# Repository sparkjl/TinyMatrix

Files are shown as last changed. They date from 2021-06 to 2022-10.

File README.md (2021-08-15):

## TinyMatrix点阵控制器
> 基于STM32F103 Microcontroller，HUB75接口的点阵控制器。可通过1 x 4按键、串口指令控制LED点阵屏显示。

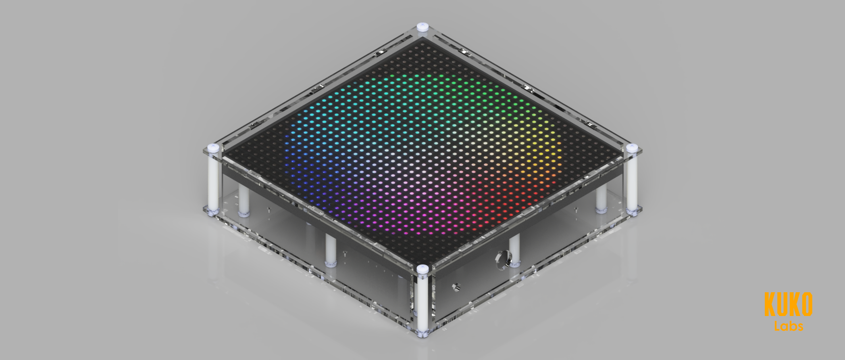
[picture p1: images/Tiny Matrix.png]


### 1. 硬件
#### 1.1. HUB75接口定义
Led点阵板的HUB75接口，一般以DC3-16P牛角座封装形式接入。通常Led点阵板的左右两侧各有一个HUB75接口IN、OUT，以实现多块Led点阵板的组合扩展。HUB75接口中：R1、G1、B1分别为上半屏的红、绿、蓝控制信号，R2、G2、B2分别为下半屏的红、绿、蓝控制信号，A、B、C、D、E为行选择信号，CLK为数据时钟信号，LAT为数据锁存信号，OE为输出使能信号，GND为信号地。

<div align="center">
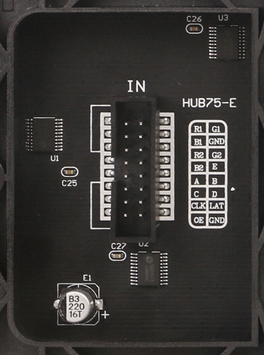
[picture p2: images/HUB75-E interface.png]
    
</div>

#### 1.2. HUB75扫描方式
将行扫描信号、行选择信号进行组合控制，就实现了整个Led点阵板的扫描显示。其具体实现过程如下：

<div align="center">
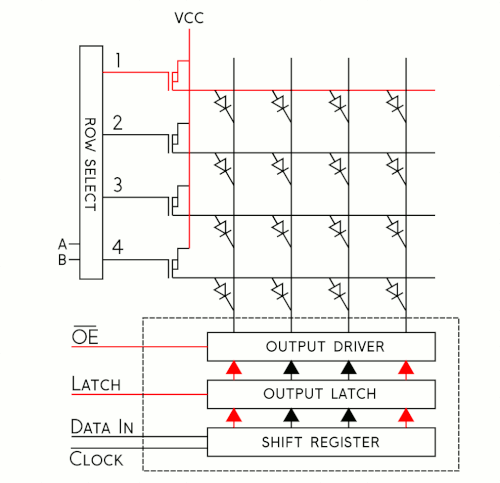
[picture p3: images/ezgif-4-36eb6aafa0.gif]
    
</div>

1. 从DATA_IN引脚（R1、G1、B1、R2、G2、B2）写入1 bit数据，将CLK引脚拉高产生上升沿将数据写入移位寄存器。如此循环m次将一行m bit数据传输至移位寄存器。
2. 将LATCH、<SPAN style="TEXT-DECORATION: overline">OE</SPAN>引脚拉高，m bit数据被从移位寄存器传输至缓存寄存器。同时缓存寄存器中数据被保持禁止从输出驱动器中输出，以使得在行选择信号切换时没有Led被点亮。
3. 切换并输出行选择信号。(初始状态时，第0行、第32行被选中。)
4. 将LATCH、<SPAN style="TEXT-DECORATION: overline">OE</SPAN>引脚拉低，m bit数据被从缓存寄存器传输至输出驱动器。同时移位寄存器中数据被锁存禁止从缓存寄存器中移出，此时对应选中行Led被点亮。

将以上步骤执行n/2次，便能实现m x n像素Led点阵板整个画面的扫描显示。如果扫描频率足够低，我们能看到逐行扫描显示的全过程：

<div align="center">
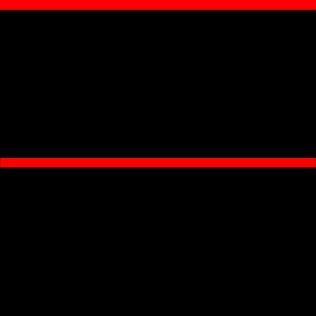
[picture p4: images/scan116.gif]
    
</div>

基于人眼视觉暂留效应（余晖效应），我们无法分辨刷新率在24Hz以上的动态画面。如果将扫描频率设置在60Hz，我们就能看到一幅完整的静态画面。而这也就是常见的显示器的基本原理。

最后，将Led点阵板上下两个部分的R1、G1、B1、R2、G2、B2控制信号进行组合，便能基于光学RGB模型实现全彩显示。

#### 1.3. Led Matrix控制板设计
了解了HUB75接口的控制原理，接下来进行Led Matrix控制板设计。

Led Matrix控制板设计思路如下：

<div align="center">
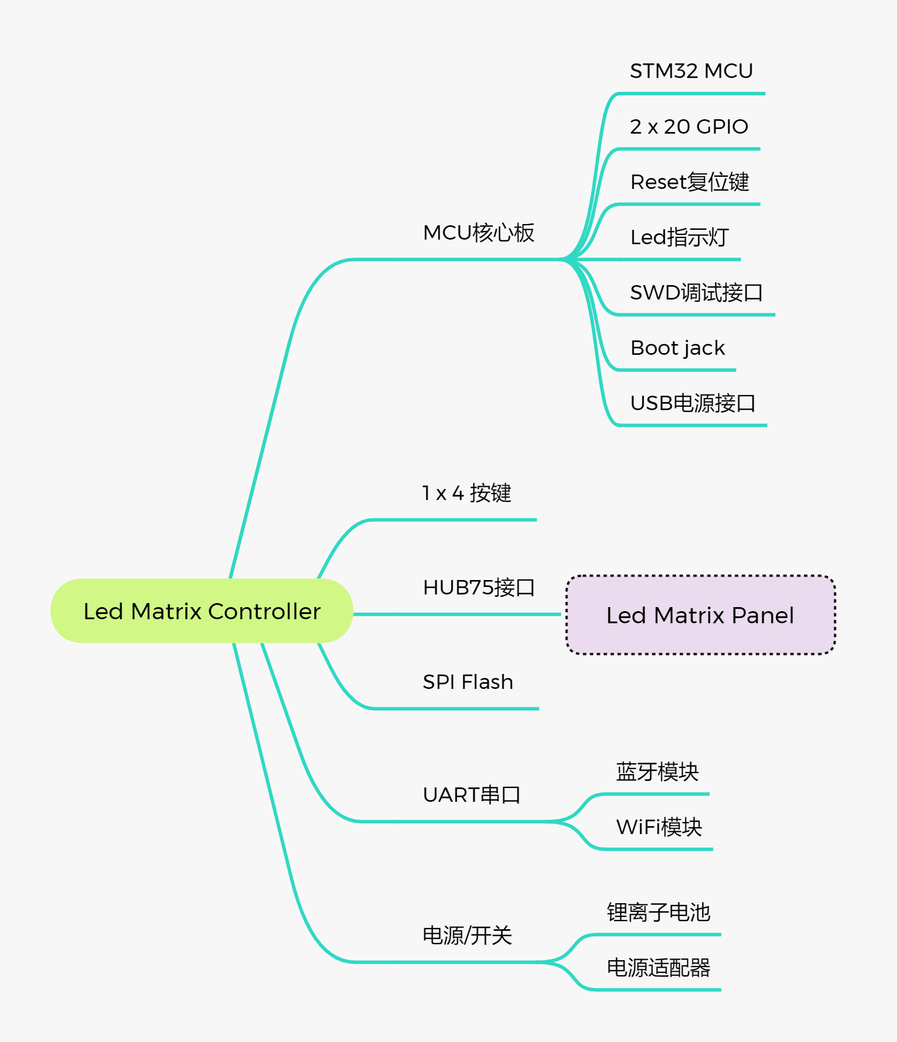
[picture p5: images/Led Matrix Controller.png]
    
</div>

Led Matrix控制板的核心选择的是一款尺寸为 22.86mm x 53.34mm 的STM32最小系统板。其通过2 x 20Pin GPIO排针将板载STM32F103C8T6 MCU内集成的2x SPI、3x USART、2x I2C、1x CAN、37x I/O、2x ADC、4x Timer等硬件资源引出，以便外围扩展板调用。固件程序可通过SWD接口进行烧录和调试，可通过Reset键复位。板载2路Led灯，一路用于电源状态指示，一路用于程序状态指示。

<div align="center">
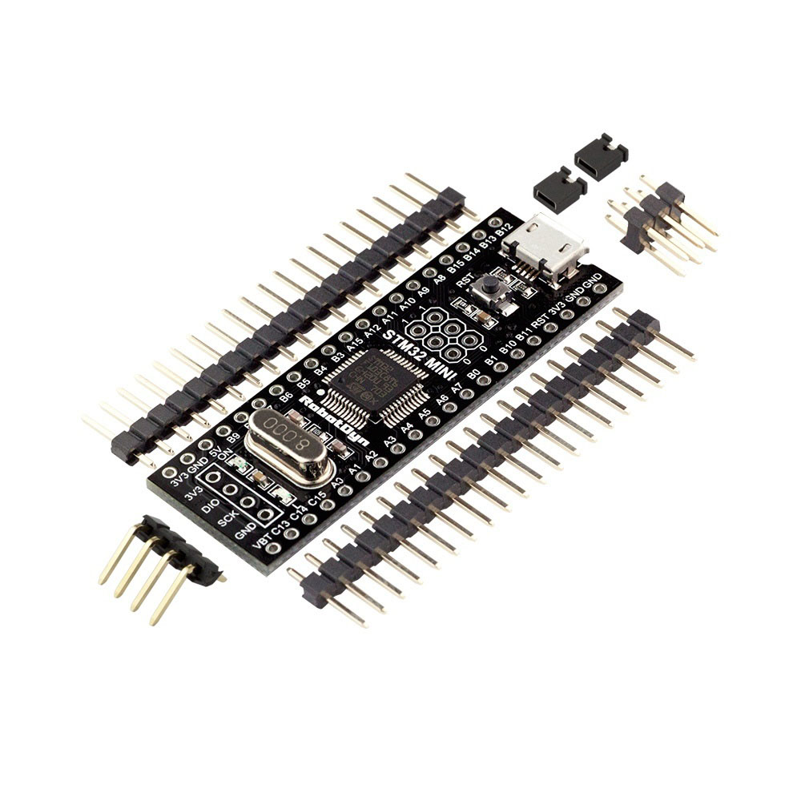
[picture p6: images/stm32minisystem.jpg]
    
</div>

Led Matrix控制板设计1 x 4按键用于点阵控制器的参数设置。MCU相关GPIO经由74HC245连接至HUB75接口，以增加驱动电流并将驱动电压从3.3v转换至5.0v。外挂的W25Qxx系列SPI Flash用于存储系统参数和字库数据。UART串口可用于下载系统参数和字库数据，TTL-蓝牙模块、TTL-WiFi模块通过UART串口建立与MCU间的通讯以实现控制指令、显示数据的无线透传。Led Matrix控制板由外接电源适配器或内置锂离子电池提供系统电源，直流降压电路实现系统电源从12v-> 5v-> 3.3v电压转换以给各功能单元供电。

基于以上硬件需求，将Led Matrix控制板通过Eagle PCB设计如下。至于为什么是Eagle PCB，那是因为其小巧精悍、简单易用，丰富的元件库、精美的原理图、标准vector字体，无不透露着严谨精致。可惜的是，被Autodesk收购后的Eagle 9.6.2对于3D模型的预览编辑需要通过Fusion 360来实现。

<div align="center">
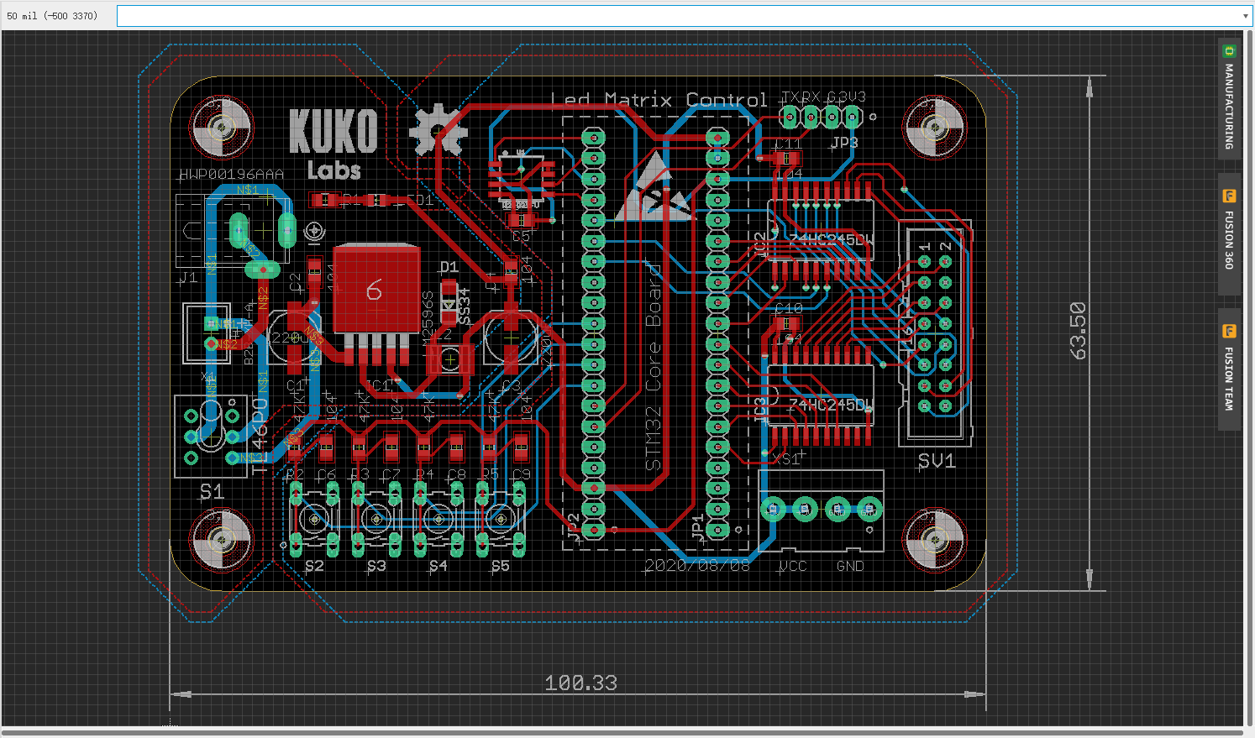
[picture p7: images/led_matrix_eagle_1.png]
    
</div>
<div align="center">
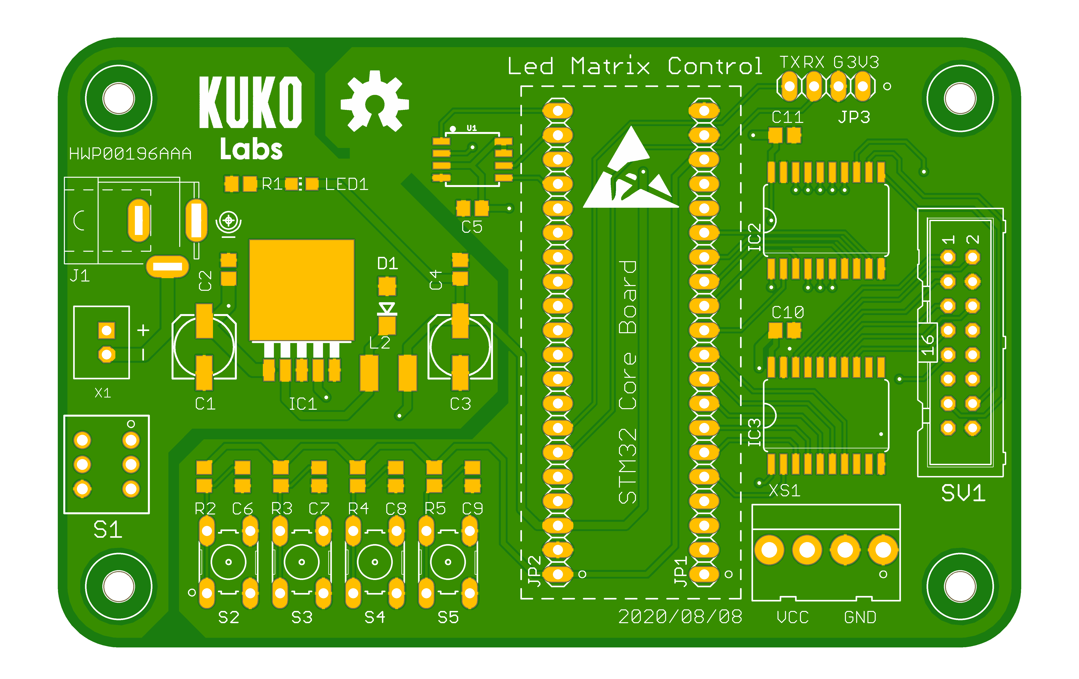
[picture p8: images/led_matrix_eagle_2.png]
    
</div>

### 2. 结构

Eagle 9.6.2不支持直接编辑3D封装，而只能通过Fusion 360以云托管元件库的方式导入。不想从Fusion 360中重构元件库，但又追求项目完整性，这怎么解决呢？那就选择KiCad，不仅支持3D封装的直接编辑，还能将Eagle的.sch原理图文件、.brd电路板文件转换成对应的KiCad格式文件。

使用KiCad将Led Matrix控制板的Eagle格式文件转换成KiCad格式文件，基于此添加编辑3D封装，导出Led Matrix控制板3D Step模型文件。

使用KiCad对MCU核心板重新进行layout，添加编辑3D封装，导出MCU核心板3D Step模型文件。

在Fusion 360中将Led Matrix控制板和MCU核心板进行零件装配、干涉检查。

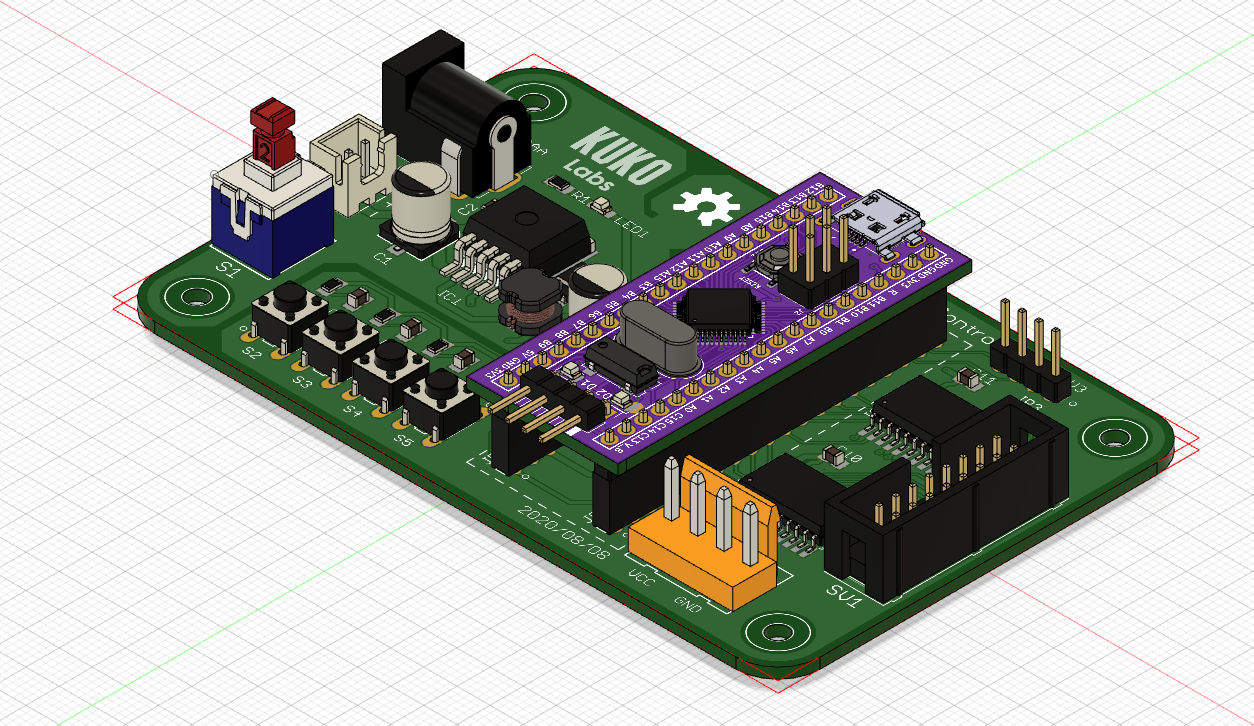
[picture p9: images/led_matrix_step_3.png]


在Fusion 360中将Led Matrix控制板设置为固定零件，以此为基准依据Led Matrix控制板的空间尺寸设计Led Matrix控制器的整体结构。选择亚克力板材作为外壳材质。顶部和底部亚克力板通过双通螺母柱进行连接，Led Matrix控制板和Led点阵板与底部亚克力板连接固定，四侧亚克力板与顶部和底部亚克力板通过卡扣扣合进行连接。

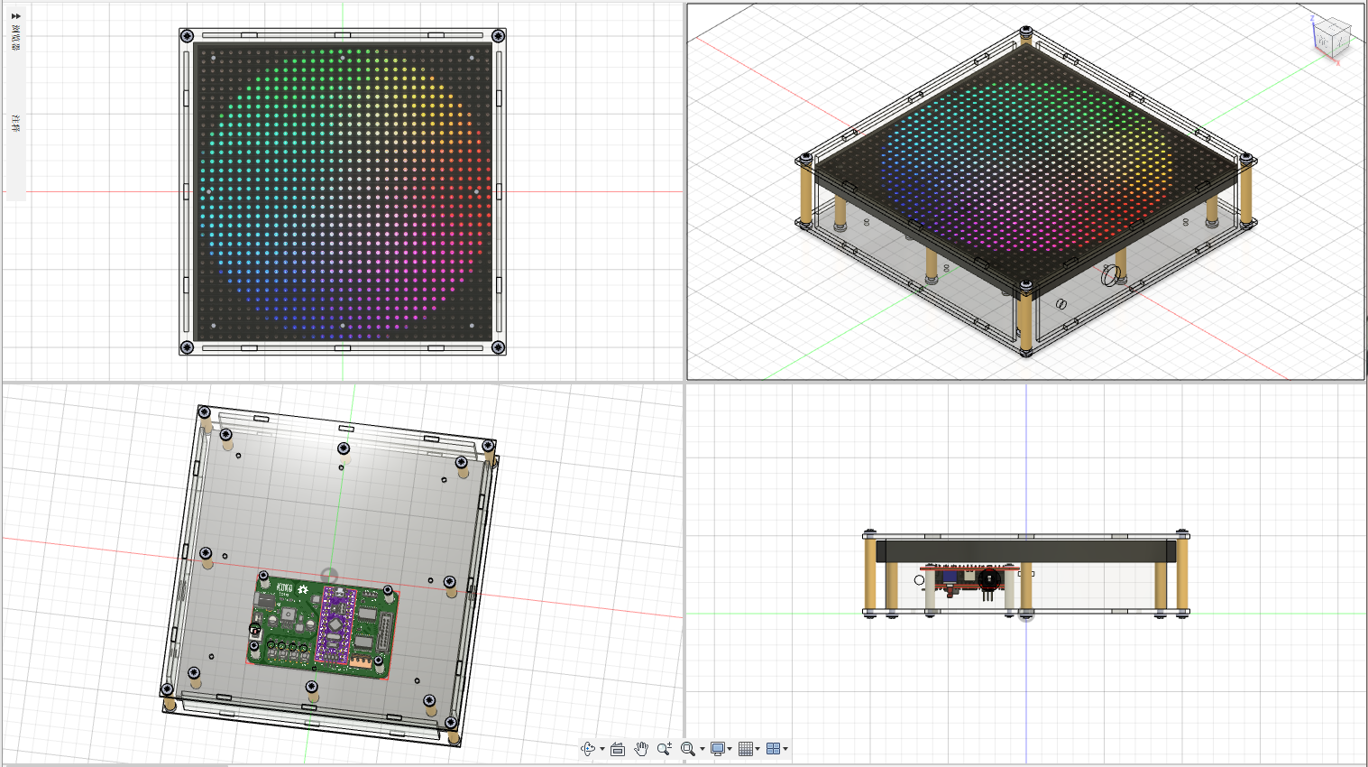
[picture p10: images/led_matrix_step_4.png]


### 3. 软件
#### 3.1. RGB LED全彩显示
控制RGB LED实现全彩显示的传统方式是脉宽调制（Pulse Width Modulation），简称PWM。通过脉宽调制控制LED开关时间占比，进而实现RGB LED的亮度调节。如果对RGB模块中的三个LED进行此操作，则可以将红绿蓝三色按比例混合成对应的RGB全彩输出。对于Led Matrix Panel的全彩显示，PWM方式却不适用：这需要足够多的GPIO和定时器独立控制，需要消耗太多的硬件资源。那么我们如何通过软件方式予以解决呢？  

二进制编码调制（Binary Code Modulation），简称BCM。BCM利用二进制编码性质控制开关信号占空比。假设有一个位宽为4的二进制数：从其最低位向左移动至最高位依次表示1个时间切片、2个时间切片、4个时间切片、8个时间切片。将这4种时间切片混合，可产生分辨率为1/15的任意占空比。如此，位宽越大分辨率越高色彩越丰富。位宽为8的二进制数，可表示分辨率为1/255的任意占空比。但位宽越大，时间切片越小，意味着更高的CPU占用率。为更好地平衡系统性能和硬件资源，本项目中BCM位宽为4。例如，4位二进制数0101表示5/15或33.3%的占空比。

<div align="center">
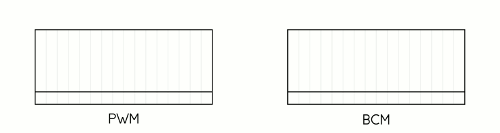
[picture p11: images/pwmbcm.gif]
    
</div>

Led Matrix Panel是逐行扫描显示的，所以需要预先将图像像素色彩转换成BCM值保存至图像缓冲区。创建4个图像缓冲区，以表示BCM位宽为4情况下的4种长度的时间切片中在扫描时间范围内哪些时间切片需要点亮LED。将这4个图像缓冲区构成的4个颜色通道Plane，进行图像融合就构成了一幅完整的静态图像。

<div align="center">
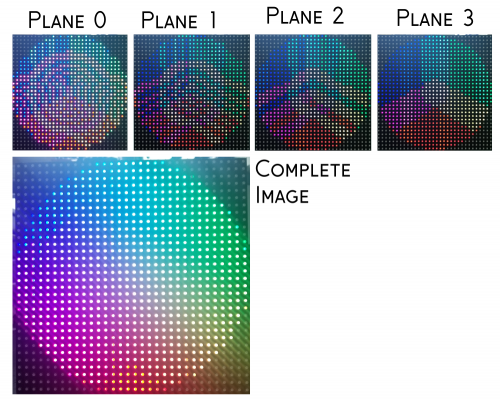
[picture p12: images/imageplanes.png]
    
</div>

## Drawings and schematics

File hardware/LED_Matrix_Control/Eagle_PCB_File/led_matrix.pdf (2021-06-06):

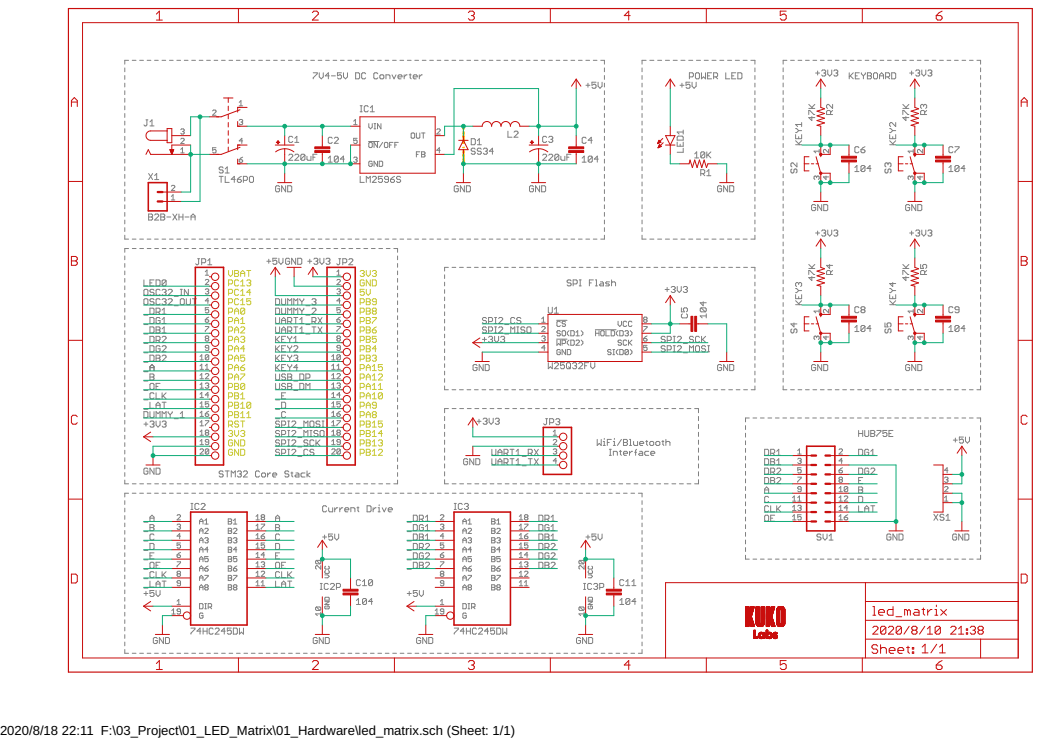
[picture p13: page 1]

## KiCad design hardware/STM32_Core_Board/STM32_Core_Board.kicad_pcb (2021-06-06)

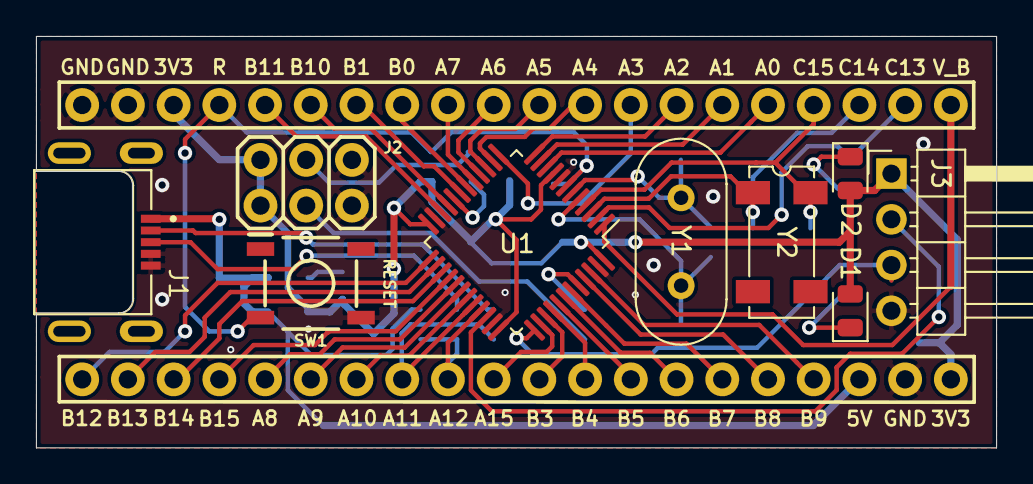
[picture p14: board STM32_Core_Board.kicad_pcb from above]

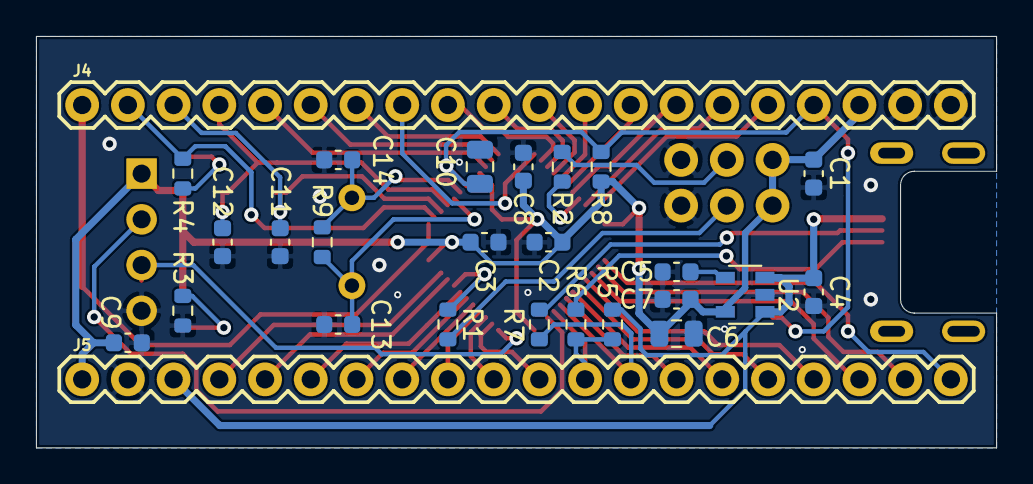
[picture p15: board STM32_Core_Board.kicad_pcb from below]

Board: 2 copper layers, 53.3 x 22.9 mm, 35 parts (26 on the bottom side), 50 nets.

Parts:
C1, C2, C3, C7, C8, C9: 104; C_0603_1608Metric
C4: 105; C_0603_1608Metric
C5: 223; C_0603_1608Metric
C6: 106; C_0805_2012Metric
C10: 105; C_0805_2012Metric
C11, C12, C13, C14: 20pF; C_0603_1608Metric
D1, D2: LED; LED_0805_2012Metric
J1: USB_B_Micro; USB_Micro-B-MOLEX_47642-0001
J2: Header 3x2; 2X3
J3: SWD; PinHeader_1x04_P2.54mm_Horizontal
J4, J5: Conn_01x20_Male; 1X20
R1, R2: 100K; R_0603_1608Metric
R3, R4: 510R; R_0603_1608Metric
R5: 4.7K; R_0603_1608Metric
R6, R7: 20R; R_0603_1608Metric
R8: 10K; R_0603_1608Metric
R9: 1M; R_0603_1608Metric
SW1: RESET; TACTILE_SWITCH_SMD_5.2MM
U1: STM32F103C8Tx; LQFP-48_7x7mm_P0.5mm
U2: SPX3819M5-L-3-3; SOT-23-5
Y1: 8MHz; Crystal_HC49-4H_Vertical
Y2: Crystal_GND23_Small; Crystal_SMD_SeikoEpson_MC306-4Pin_8.0x3.2mm

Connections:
+3V3: C1.1, C2.1, C3.1, C6.1, C7.1, C8.1, C9.1, D1.2, D2.2, J2.1, J2.2, J3.1, J4.18, J5.1, R8.1, U1.9, U1.24, U1.36, U1.48, U2.5
+5V: C4.1, J1.1, J5.3, R5.2, U2.1, U2.3
/BOOT0: R1.1, U1.44
/BOOT1: R2.2, U1.20
/OSCIN: C13.1, R9.1, U1.5, Y1.1
/OSCOUT: C14.1, R9.2, U1.6, Y1.2
/PA0: J4.5, U1.10
/PA1: J4.6, U1.11
/PA2: J4.7, U1.12
/PA3: J4.8, U1.13
/PA4: J4.9, U1.14
/PA5: J4.10, U1.15
/PA6: J4.11, U1.16
/PA7: J4.12, U1.17
/PA8: J5.16, U1.29
/PA9: J5.15, U1.30
/PA10: J5.14, U1.31
/PA11: J5.13, R7.1, U1.32
/PA12: J5.12, R5.1, R6.1, U1.33
/PA13: J3.2, U1.34
/PA14: J3.3, U1.37
/PA15: J5.11, U1.38
/PB0: J4.13, U1.18
/PB1: J4.14, U1.19
/PB3: J5.10, U1.39
/PB4: J5.9, U1.40
/PB5: J5.8, U1.41
/PB6: J5.7, U1.42
/PB7: J5.6, U1.43
/PB8: J5.5, U1.45
/PB9: J5.4, U1.46
/PB10: J4.15, U1.21
/PB11: J4.16, U1.22
/PB12: J5.20, U1.25
/PB13: J5.19, U1.26
/PB14: J5.18, U1.27
/PB15: J5.17, U1.28
/PC13: J4.2, R4.1, U1.2
/PC14: C11.1, J4.3, U1.3, Y2.1
/PC15: C12.1, J4.4, U1.4, Y2.4
/RESET: C10.1, J4.17, R8.2, SW1.2, U1.7
GND: C1.2, C2.2, C3.2, C4.2, C5.2, C6.2, C7.2, C8.2, C9.2, C10.2, C11.2, C12.2, C13.2, C14.2, J1.4, J1.5, J2.5, J2.6, J3.4, J4.19, J4.20, J5.2, R3.1, SW1.1, U1.8, U1.23, U1.35, U1.47, U2.2
unnamed: C5.1, U2.4
unnamed: D1.1, R3.2
unnamed: D2.1, R4.2
unnamed: J1.2, R7.2
unnamed: J1.3, R6.2
unnamed: J2.3, R1.2
unnamed: J2.4, R2.1
V_BATT: J4.1, U1.1

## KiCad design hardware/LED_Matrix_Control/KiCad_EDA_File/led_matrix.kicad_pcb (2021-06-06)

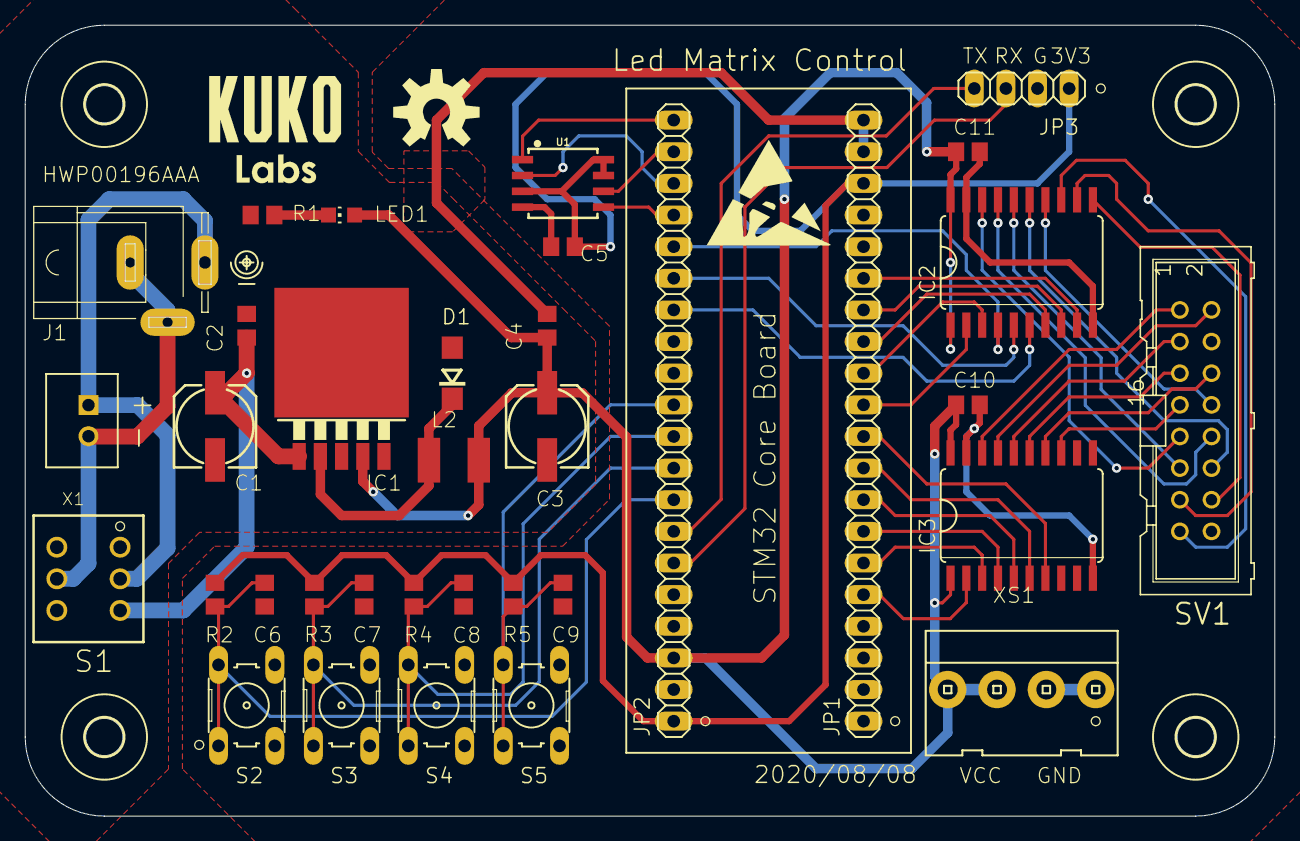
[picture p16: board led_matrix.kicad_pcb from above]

Board: 2 copper layers, 100.3 x 63.5 mm, 42 parts (0 on the bottom side), 46 nets.

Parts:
C1, C3: 220uF; 153CLV-0605
C2, C4, C5, C6, C7, C8, C9, C10, C11: 104; C0805
D1: SS34; DO214AC
IC1: LM2596S; TO263-5
IC2, IC3: 74245DW; SO20W
J1: JACK-PLUG0; SPC4077
JP1, JP2: PINHD-1X20; 1X20
JP3: PINHD-1X4; 1X04
L2: L-USL4532P; L4532P
LED1: LEDCHIP-LED0805; CHIP-LED0805
R1: 10K; R0805
R2, R3, R4, R5: 47K; R0805
S1: TL46PO; TL4XPO
S2, S3, S4, S5: 10-XX; B3F-10XX
SV1: ML16
U1: W25Q32FV; SOIC-8
U$1: LOGO?; LOGO
U$2, U$3, U$4, U$5: 3,0
U$6: ESD_10.00
U$7: OSHW-LOGO-L
X1: B2B-XH-A
XS1: C4; NINIGI4C

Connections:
+3V3: C5.1, JP1.18, JP2.1, JP3.1, R2.1, R3.1, R4.1, R5.1, U1.3, U1.7, U1.8
+5V: C3.+, C4.1, C10.1, C11.1, IC1.4, IC2.1, IC2.20, IC3.1, IC3.20, JP2.3, L2.2, LED1.A, XS1.3, XS1.4
/A: IC2.18, SV1.9
/B: IC2.17, SV1.10
/C: IC2.16, SV1.11
/CLK: IC2.12, SV1.13
/D: IC2.15, SV1.12
/DB1: IC3.16, SV1.3
/DB2: IC3.13, SV1.7
/DG1: IC3.17, SV1.2
/DG2: IC3.14, SV1.6
/DR1: IC3.18, SV1.1
/DR2: IC3.15, SV1.5
/E: IC2.14, SV1.8
/KEY1: C6.1, JP2.8, R2.2, S2.1, S2.2
/KEY2: C7.1, JP2.9, R3.2, S3.1, S3.2
/KEY3: C8.1, JP2.10, R4.2, S4.1, S4.2
/KEY4: C9.1, JP2.11, R5.2, S5.1, S5.2
/LAT: IC2.11, SV1.14
/OE: IC2.13, SV1.15
/SPI2_CS: JP2.20, U1.1
/SPI2_MISO: JP2.18, U1.2
/SPI2_MOSI: JP2.17, U1.5
/SPI2_SCK: JP2.19, U1.6
/UART1_RX: JP2.6, JP3.3
/UART1_TX: JP2.7, JP3.4
/_A: IC2.2, JP1.11
/_B: IC2.3, JP1.12
/_C: IC2.4, JP2.16
/_CLK: IC2.8, JP1.14
/_D: IC2.5, JP2.15
/_DB1: IC3.4, JP1.7
/_DB2: IC3.7, JP1.10
/_DG1: IC3.3, JP1.6
/_DG2: IC3.6, JP1.9
/_DR1: IC3.2, JP1.5
/_DR2: IC3.5, JP1.8
/_E: IC2.6, JP2.14
/_LAT: IC2.9, JP1.15
/_OE: IC2.7, JP1.13
GND: C1.-, C2.2, C3.-, C4.2, C5.2, C6.2, C7.2, C8.2, C9.2, C10.2, C11.2, D1.A, IC1.3, IC1.5, IC2.10, IC2.19, IC3.10, IC3.19, JP1.19, JP1.20, JP2.2, JP3.2, R1.1, S1.6, S2.3, S2.4, S3.3, S3.4, S4.3, S4.4, S5.3, S5.4, SV1.4, SV1.16, U1.4, XS1.1, XS1.2
unnamed: C1.+, C2.1, IC1.1, S1.3
unnamed: D1.C, IC1.2, L2.1
unnamed: J1.1, J1.2, S1.5, X1.2
unnamed: J1.3, S1.2, X1.1
unnamed: LED1.C, R1.2

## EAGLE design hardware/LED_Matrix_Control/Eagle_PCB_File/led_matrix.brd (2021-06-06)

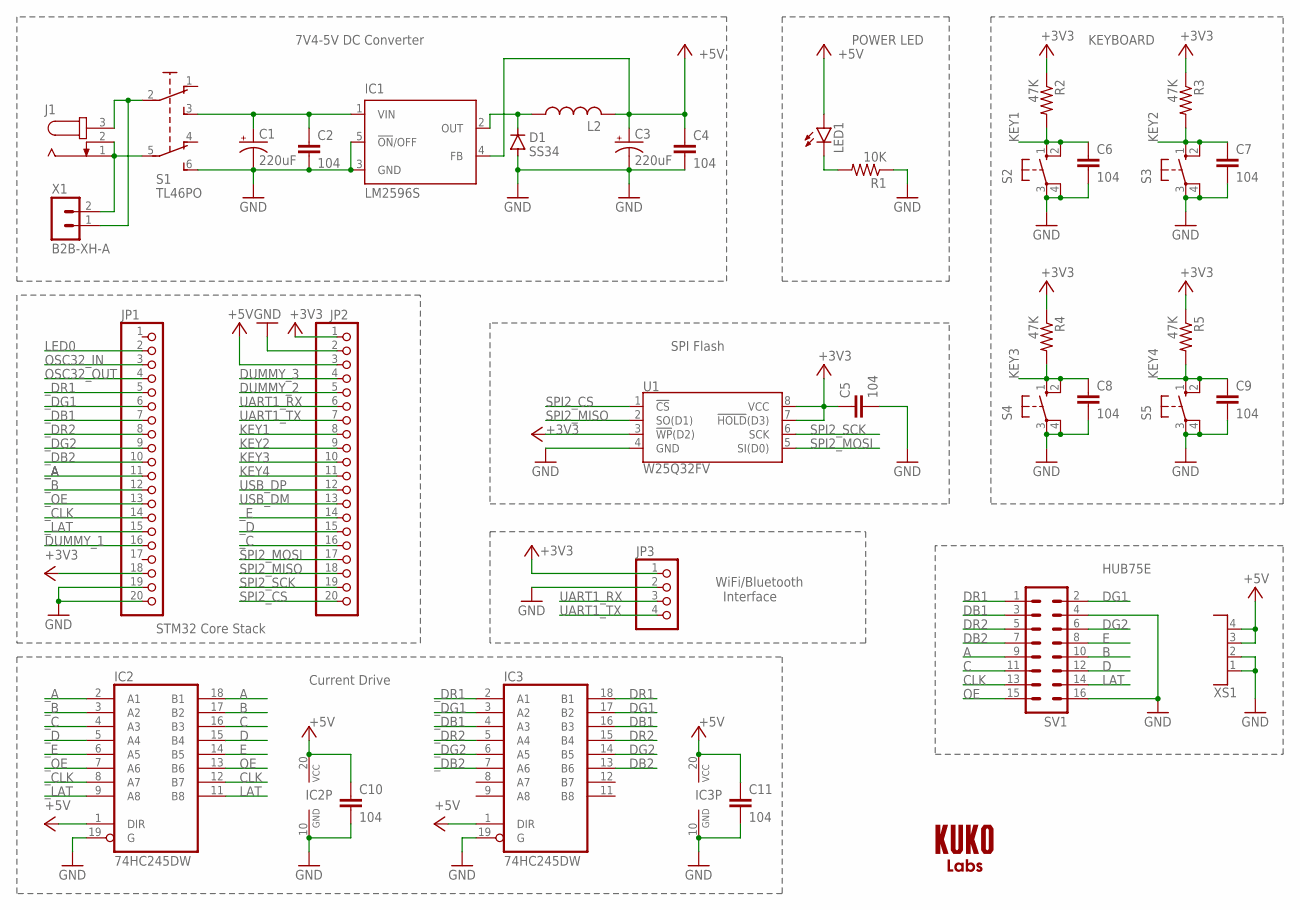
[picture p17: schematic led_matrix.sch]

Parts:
C1, C3: 220uF; 153CLV-0605
C2, C4, C5, C6, C7, C8, C9, C10, C11: 104; C0805
D1: SS34; DO214AC
IC1: LM2596S; TO263-5
IC2, IC3: 74HC245DW; SO20W
J1: JACK-PLUG0; SPC4077
JP1, JP2: PINHD-1X20; 1X20
JP3: PINHD-1X4; 1X04
L2: L-USL4532P; L4532P
LED1: LEDCHIP-LED0805; CHIP-LED0805
R1: 10K; R0805
R2, R3, R4, R5: 47K; R0805
S1: TL46PO; TL4XPO
S2, S3, S4, S5: 10-XX; B3F-10XX
SV1: ML16
U1: W25Q32FV; SOIC-8
U$1: LOGO
X1: B2B-XH-A
XS1: C4; NINIGI4C

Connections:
+3V3: C5.1, JP1.18, JP2.1, JP3.1, R2.1, R3.1, R4.1, R5.1, U1.3 (!WP!(D2)), U1.7 (!HOLD!(D3)), U1.8 (VCC)
+5V: C3.+, C4.1, C10.1, C11.1, IC1.4 (FB), IC2.1 (DIR), IC2.20 (VCC), IC3.1 (DIR), IC3.20 (VCC), JP2.3, L2.2, LED1.A, XS1.3, XS1.4
A: IC2.18 (B1), SV1.9
B: IC2.17 (B2), SV1.10
C: IC2.16 (B3), SV1.11
CLK: IC2.12 (B7), SV1.13
D: IC2.15 (B4), SV1.12
DB1: IC3.16 (B3), SV1.3
DB2: IC3.13 (B6), SV1.7
DG1: IC3.17 (B2), SV1.2
DG2: IC3.14 (B5), SV1.6
DR1: IC3.18 (B1), SV1.1
DR2: IC3.15 (B4), SV1.5
DUMMY_1: JP1.16
DUMMY_2: JP2.5
DUMMY_3: JP2.4
E: IC2.14 (B5), SV1.8
GND: C1.-, C2.2, C3.-, C4.2, C5.2, C6.2, C7.2, C8.2, C9.2, C10.2, C11.2, D1.A, IC1.3 (GND), IC1.5 (!ON!/OFF), IC2.10 (GND), IC2.19 (G), IC3.10 (GND), IC3.19 (G), JP1.19, JP1.20, JP2.2, JP3.2, R1.1, S1.6 (S1), S2.3, S2.4 (P1), S3.3, S3.4 (P1), S4.3, S4.4 (P1), S5.3, S5.4 (P1), SV1.4, SV1.16, U1.4 (GND), XS1.1, XS1.2
KEY1: C6.1, JP2.8, R2.2, S2.1 (S), S2.2 (S1)
KEY2: C7.1, JP2.9, R3.2, S3.1 (S), S3.2 (S1)
KEY3: C8.1, JP2.10, R4.2, S4.1 (S), S4.2 (S1)
KEY4: C9.1, JP2.11, R5.2, S5.1 (S), S5.2 (S1)
LAT: IC2.11 (B8), SV1.14
LED0: JP1.2
unnamed: J1.3, S1.2, X1.1
unnamed: J1.1, J1.2, S1.5 (P1), X1.2
unnamed: C1.+, C2.1, IC1.1 (VIN), S1.3 (S)
unnamed: D1.C, IC1.2 (OUT), L2.1
unnamed: LED1.C, R1.2
OE: IC2.13 (B6), SV1.15
OSC32_IN: JP1.3
OSC32_OUT: JP1.4
SPI2_CS: JP2.20, U1.1 (!CS!)
SPI2_MISO: JP2.18, U1.2 (SO(D1))
SPI2_MOSI: JP2.17, U1.5 (SI(D0))
SPI2_SCK: JP2.19, U1.6 (SCK)
UART1_RX: JP2.6, JP3.3
UART1_TX: JP2.7, JP3.4
USB_DM: JP2.13
USB_DP: JP2.12
_A: IC2.2 (A1), JP1.11
_B: IC2.3 (A2), JP1.12
_C: IC2.4 (A3), JP2.16
_CLK: IC2.8 (A7), JP1.14
_D: IC2.5 (A4), JP2.15
_DB1: IC3.4 (A3), JP1.7
_DB2: IC3.7 (A6), JP1.10
_DG1: IC3.3 (A2), JP1.6
_DG2: IC3.6 (A5), JP1.9
_DR1: IC3.2 (A1), JP1.5
_DR2: IC3.5 (A4), JP1.8
_E: IC2.6 (A5), JP2.14
_LAT: IC2.9 (A8), JP1.15
_OE: IC2.7 (A6), JP1.13

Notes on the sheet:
POWER LED
7V4-5V DC Converter
KEYBOARD
HUB75E
SPI Flash
STM32 Core Stack
Current Drive
WiFi/Bluetooth Interface

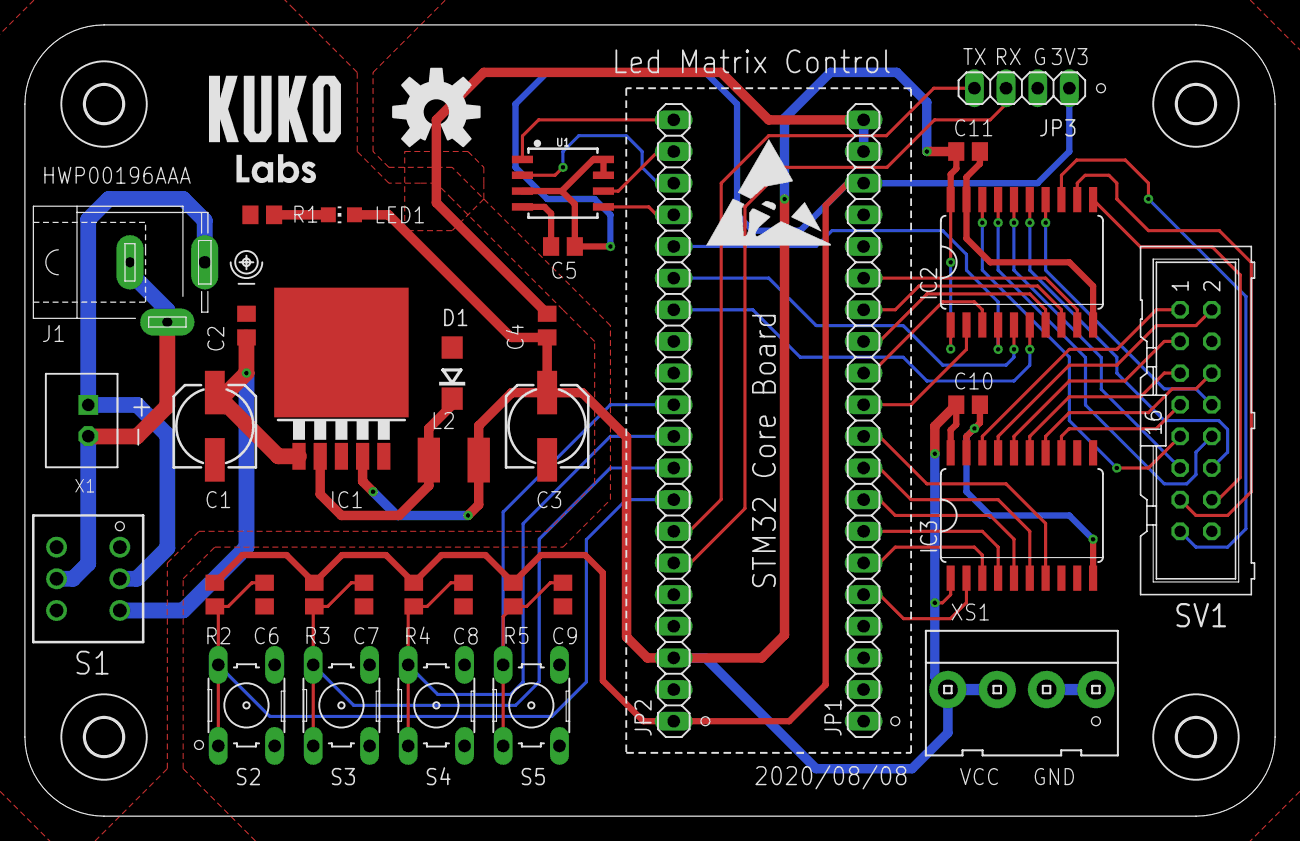
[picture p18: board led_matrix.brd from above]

Board: 2 copper layers, 100.3 x 63.5 mm, 42 parts (0 on the bottom side), 46 nets.

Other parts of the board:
U$2, U$3, U$4, U$5: 3,0
U$6: ESD_10.00
U$7: OSHW-LOGO-L

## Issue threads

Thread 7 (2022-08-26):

请问在哪里配置扫描数？我没有看到扫描数。代码支持的灯板是默认64扫描的吗？

Loufey, 2022-08-26:
hi，你的代码逻辑写的很棒！
我有几个问题想请教一下：
●请问在哪里配置灯板的扫描数？我没有看到扫描数。代码支持的灯板是默认64扫描的吗？如果我想配置成8扫的，应该在哪里修改参数配置。另外关于LED驱动芯片的数量配置，我也没有找到，我想请问一下你用的灯板是有多少个LED驱动芯片。
●在hub75_buff[HUB75_PANEL_WIDTH/8 * HUB75_PANEL_HEIGHT]这条语句中， HUB75_PANEL_WIDTH/8 * HUB75_PANEL_HEIGHT 是什么含义 是每帧像素点的数量吗？
●如果我的灯板是48X32分辨率，长48高32，8扫。应该如何配置参数

以上，谢谢！

sparkjl, 2022-09-03:
@Loufey
本项目是64x64/32扫的led matrix。8扫的led matrix只有A、B、C 3根地址线，需要将`HUB75_PANEL_HEIGHT`设置为16（上下1/2屏各8行）。注意此处是显存buffer height，可能并不是matrix height。如果`HUB75_PANEL_HEIGHT` = matrix height / n，则`HUB75_PANEL_WIDTH` = matrix width * n。因为led matrix生产商可能会将原本1行的led layout到n行。如果led driver为SM1612，则只需要将`HUB75_PANEL_HEIGHT`设置为16；而如果led driver为ICN2053/ICN2153，则先需要配置相关寄存器，行扫描函数也需要修改。

chip number是扫描1行led所需要的led driver数量。你问到这里，说明你的led driver为ICN2053/ICN2153，这是一种16bit移位输出芯片。因为上下1/2屏R/G/B数据线是独立的，所以total chip number = `HUB75_PANEL_WIDTH` / 16 * 2。

`hub75_buff`可以理解为显存，这里主要用于字符显示。led matrix通常是横向扫描，考虑到字库格式及SM1612这类led driver都是8bit移位输出芯片，所以`hub75_buff`大小为`HUB75_PANEL_WIDTH`/8 * `HUB75_PANEL_HEIGHT`。

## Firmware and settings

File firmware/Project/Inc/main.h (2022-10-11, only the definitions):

#define LED1_Pin GPIO_PIN_13
#define LED1_GPIO_Port GPIOC
#define HUB75_DR1_Pin GPIO_PIN_0
#define HUB75_DR1_GPIO_Port GPIOA
#define HUB75_DG1_Pin GPIO_PIN_1
#define HUB75_DG1_GPIO_Port GPIOA
#define HUB75_DB1_Pin GPIO_PIN_2
#define HUB75_DB1_GPIO_Port GPIOA
#define HUB75_DR2_Pin GPIO_PIN_3
#define HUB75_DR2_GPIO_Port GPIOA
#define HUB75_DG2_Pin GPIO_PIN_4
#define HUB75_DG2_GPIO_Port GPIOA
#define HUB75_DB2_Pin GPIO_PIN_5
#define HUB75_DB2_GPIO_Port GPIOA
#define HUB75_A_Pin GPIO_PIN_6
#define HUB75_A_GPIO_Port GPIOA
#define HUB75_B_Pin GPIO_PIN_7
#define HUB75_B_GPIO_Port GPIOA
#define HUB75_OE_Pin GPIO_PIN_0
#define HUB75_OE_GPIO_Port GPIOB
#define HUB75_CLK_Pin GPIO_PIN_1
#define HUB75_CLK_GPIO_Port GPIOB
#define HUB75_LAT_Pin GPIO_PIN_10
#define HUB75_LAT_GPIO_Port GPIOB
#define SPI2_CS_Pin GPIO_PIN_12
#define SPI2_CS_GPIO_Port GPIOB
#define HUB75_C_Pin GPIO_PIN_8
#define HUB75_C_GPIO_Port GPIOA
#define HUB75_D_Pin GPIO_PIN_9
#define HUB75_D_GPIO_Port GPIOA
#define HUB75_E_Pin GPIO_PIN_10
#define HUB75_E_GPIO_Port GPIOA
#define KEY_4_Pin GPIO_PIN_15
#define KEY_4_GPIO_Port GPIOA
#define KEY_3_Pin GPIO_PIN_3
#define KEY_3_GPIO_Port GPIOB
#define KEY_2_Pin GPIO_PIN_4
#define KEY_2_GPIO_Port GPIOB
#define KEY_1_Pin GPIO_PIN_5
#define KEY_1_GPIO_Port GPIOB

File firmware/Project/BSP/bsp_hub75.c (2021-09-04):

#include "includes.h"

uint8_t hub75_buff[HUB75_PANEL_WIDTH/8 * HUB75_PANEL_HEIGHT];
uint8_t hub75_color = HUB75_Color_Pink;
uint8_t hub75_blink = 0;

uint8_t hub75_panel_buff[HUB75_PANEL_WIDTH * HUB75_PANEL_HEIGHT / 2 * 3];

void send_clock(void)
{
  HUB75_CLK_H();
  HUB75_CLK_L();
}

void send_latch(unsigned char clock)
{
  HUB75_LAT_H();
  while(clock--)
  {
    send_clock();
  }
  HUB75_LAT_L();
}

void send_pwm_cycle(unsigned char cycle)
{
  while(cycle--)
  {
    HUB75_OE_H();
    HUB75_OE_L();
  }
}

void send_scan_line(unsigned char line)
{
  (line & 0x0001) ? HUB75_A_H() : HUB75_A_L();
  (line & 0x0002) ? HUB75_B_H() : HUB75_B_L();
  (line & 0x0004) ? HUB75_C_H() : HUB75_C_L();
  (line & 0x0008) ? HUB75_D_H() : HUB75_D_L();
  (line & 0x0010) ? HUB75_E_H() : HUB75_E_L();
}

void send_config(unsigned int data, unsigned char clock)
{
  unsigned char num = HUB75_PANEL_WIDTH/16;      // chip number
  unsigned int mask = 0x8000;

  clock = 16 - clock;

  while(num--)
  {
    for(unsigned char bit=0; bit<16; bit++)
    {
      mask = 0x8000 >> bit;

      if(data & mask)
      {
        HUB75_DR1_H();
        HUB75_DG1_H();
        HUB75_DB1_H();
        HUB75_DR2_H();
        HUB75_DG2_H();
        HUB75_DB2_H();
      }
      else
      {
        HUB75_DR1_L();
        HUB75_DG1_L();
        HUB75_DB1_L();
        HUB75_DR2_L();
        HUB75_DG2_L();
        HUB75_DB2_L();
      }

      if(num == 0 && bit == clock)
        HUB75_LAT_H();
      send_clock();
    }

    HUB75_LAT_L();
  }
}

void bsp_hub75_init(void)
{
  HUB75_OE_H();
  HUB75_CLK_L();
  HUB75_LAT_L();

  HUB75_DR1_L();
  HUB75_DG1_L();
  HUB75_DB1_L();
  HUB75_DR2_L();
  HUB75_DG2_L();
  HUB75_DB2_L();

  HUB75_A_L();
  HUB75_B_L();
  HUB75_C_L();
  HUB75_D_L();
  HUB75_E_L();

#if HUB75_DRIVER_TYPE == 2
  /* Configure SRAM */
  send_latch(14);      // Pre-Active command
  send_latch(12);      // Enable all output channels
  send_latch(3);       // Vertical Sync
  send_latch(14);      // Pre-Active command
  send_config(0x1F70, 4);                  // Write config register 1 (4 latches)
  send_latch(14);      // Pre-Active command
  send_config(0xffff, 6);                  // Write config register 2 (6 latches)
  send_latch(14);      // Pre-Active command
  send_config(0x40F3, 8);                  // Write config register 3 (8 latches)
  send_latch(14);      // Pre-Active command
  send_config(0x0000, 10);                 // Write config register 4 (10 latches)
  send_latch(14);      // Pre-Active command
  send_config(0x0000, 2);                  // Write debug register (2 latches)
#endif

#if 1
  for(uint8_t i=0;i<32;i++)
  {
    for(uint8_t j=0;j<32;j++)
    {
      bsp_hub75_write_panel(255,153,0,i,j);
    }
    for(uint8_t k=32;k<64;k++)
    {
      bsp_hub75_write_panel(102,255,204,i,k);
    }
  }

  for(uint8_t i=32;i<64;i++)
  {
    for(uint8_t j=0;j<64;j++)
    {
      bsp_hub75_write_panel(255,0,255,i,j);
    }
  }
#endif
}

#if HUB75_DRIVER_TYPE == 0
void bsp_hub75_write_byte(uint8_t p_buff[], uint8_t color)
{
  static uint16_t row = 0;
  uint8_t data_r1, data_g1, data_b1, data_r2, data_g2, data_b2 = 0;

  /* write column data */
  for(uint16_t i=0; i<(HUB75_PANEL_WIDTH/8); i++)
  {
    data_r1 = data_g1 = data_b1 = 0;
    data_r2 = data_g2 = data_b2 = 0;

    /* color red */
    if(color & 0x01)
    {
      data_b1 = p_buff[row*(HUB75_PANEL_WIDTH/8)+i];
      data_b2 = p_buff[row*(HUB75_PANEL_WIDTH/8)+(HUB75_PANEL_WIDTH/8*HUB75_PANEL_HEIGHT/2)+i];
    }

    /* color green */
    if(color & 0x02)
    {
      data_r1 = p_buff[row*(HUB75_PANEL_WIDTH/8)+i];
      data_r2 = p_buff[row*(HUB75_PANEL_WIDTH/8)+(HUB75_PANEL_WIDTH/8*HUB75_PANEL_HEIGHT/2)+i];
    }

    /* color blue */
    if(color & 0x04)
    {
      data_g1 = p_buff[row*(HUB75_PANEL_WIDTH/8)+i];
      data_g2 = p_buff[row*(HUB75_PANEL_WIDTH/8)+(HUB75_PANEL_WIDTH/8*HUB75_PANEL_HEIGHT/2)+i];
    }

    /* horizontal 8 bits data */
    for(uint8_t k=0; k<8; k++)
    {
      ((data_r1>>(7-k)) & 0x01) ? HUB75_DR1_H() : HUB75_DR1_L();
      ((data_g1>>(7-k)) & 0x01) ? HUB75_DG1_H() : HUB75_DG1_L();
      ((data_b1>>(7-k)) & 0x01) ? HUB75_DB1_H() : HUB75_DB1_L();
      ((data_r2>>(7-k)) & 0x01) ? HUB75_DR2_H() : HUB75_DR2_L();
      ((data_g2>>(7-k)) & 0x01) ? HUB75_DG2_H() : HUB75_DG2_L();
      ((data_b2>>(7-k)) & 0x01) ? HUB75_DB2_H() : HUB75_DB2_L();

      HUB75_CLK_L();
      HUB75_CLK_H();
    }
  }

  HUB75_OE_H();
  HUB75_LAT_H();

  /* write row addr */
  (row & 0x0001) ? HUB75_A_H() : HUB75_A_L();
  (row & 0x0002) ? HUB75_B_H() : HUB75_B_L();
  (row & 0x0004) ? HUB75_C_H() : HUB75_C_L();
  (row & 0x0008) ? HUB75_D_H() : HUB75_D_L();
  (row & 0x0010) ? HUB75_E_H() : HUB75_E_L();
  HUB75_LAT_L();
  HUB75_OE_L();

  if(++row >= (HUB75_PANEL_HEIGHT/2))
    row = 0;

}
#endif
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

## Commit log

2021-06-06 draft commit
    [STM32_Core_Board-B_Cu.gbr, STM32_Core_Board-B_Mask.gbr, STM32_Core_Board-B_Paste.gbr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]
2021-06-14 hub75 timing control via Timer TIM2
2021-07-11 add uart link protocol, modify crc16 check algorithm.
2021-07-18 uart link: restart uart rx before restart uart tx
2021-08-23 draft commit: driver for ICN2053
2021-08-29 driver for ICN2053/ICN2153
2022-10-11 1.upgrade the firmware package to STM32Cube_FW_F1_V1.8.4 2.enlarge the capacity of heap and stack

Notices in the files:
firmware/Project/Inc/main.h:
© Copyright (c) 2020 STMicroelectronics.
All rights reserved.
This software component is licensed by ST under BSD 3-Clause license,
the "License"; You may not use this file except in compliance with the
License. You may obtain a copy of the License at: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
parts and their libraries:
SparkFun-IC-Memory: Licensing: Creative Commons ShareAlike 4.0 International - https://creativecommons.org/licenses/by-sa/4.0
